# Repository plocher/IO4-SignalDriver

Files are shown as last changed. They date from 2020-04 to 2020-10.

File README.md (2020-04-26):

# IO4-SignalDriver
## License: CERN Open Hardware Licence v1.2

IO4 Output adapter driver for a 2-head signal mast

Takes an IO4-Output and drives 2x 3-LED common Anode signal heads using a demultiplexor logic chip.

Designed in conjunction with Jay Beckham for his South Shore Lines layout

Circuit testing:
  * The board needs to share a common ground with the remote controller (CMRI SMINI...) as the RJ45 only carries control signals
  * Drive the board with 5V DC through the IO4 connection
  * Signal heads / LEDs are "common anode" - pin4 of the signal head connector is VCC, the "colors" pins are driven LOW to energize the LED.
  * All control lines are pulled up logically on the signal driver board.
  * The board can drive 2x signal heads, each with R, Y, G and DARK aspects
      * Control signals 1 & 2 and  3 & 4, each control one head:
          : 00 - Green
          : 01 - Yellow
          : 10 - Red
          : 11 - Dark
  * The discrete resistors set a safe limit on the current allowed to the LED, and the trimmer pots can be used to further adjust the brightness.
  * The exact value depends on the specific attributes of the LED variety being used - specifically the forward voltage drop across the device. This info is found in the data sheet for the LED in question, or can be found experimentally.
      * Example:  with a 5v supply and a LED that drops 2.2v, the resistor sees (5-2.2 = 2.8v).  If we wish to limit the max current to 15mA, we need a fixed resistor of (2.8v / 0.015 = ~180 ohms).  If we add a 500 ohn trimmer resistor, that lets us adjust the current from 15mA max to about 4mA min.  High efficiency LEDs might need even LESS current, so upping the fixed resistor to 470R or even 1K0 might be appropriate.

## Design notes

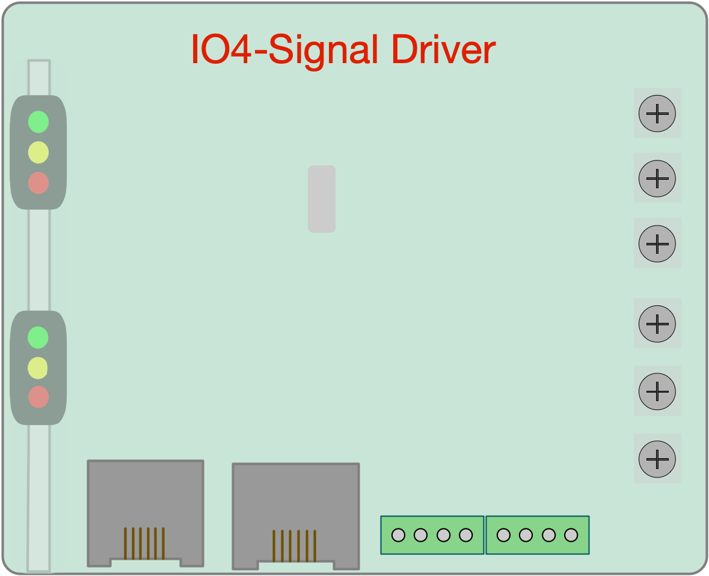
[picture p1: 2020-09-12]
IO4-SignalDriver-Graphic.png

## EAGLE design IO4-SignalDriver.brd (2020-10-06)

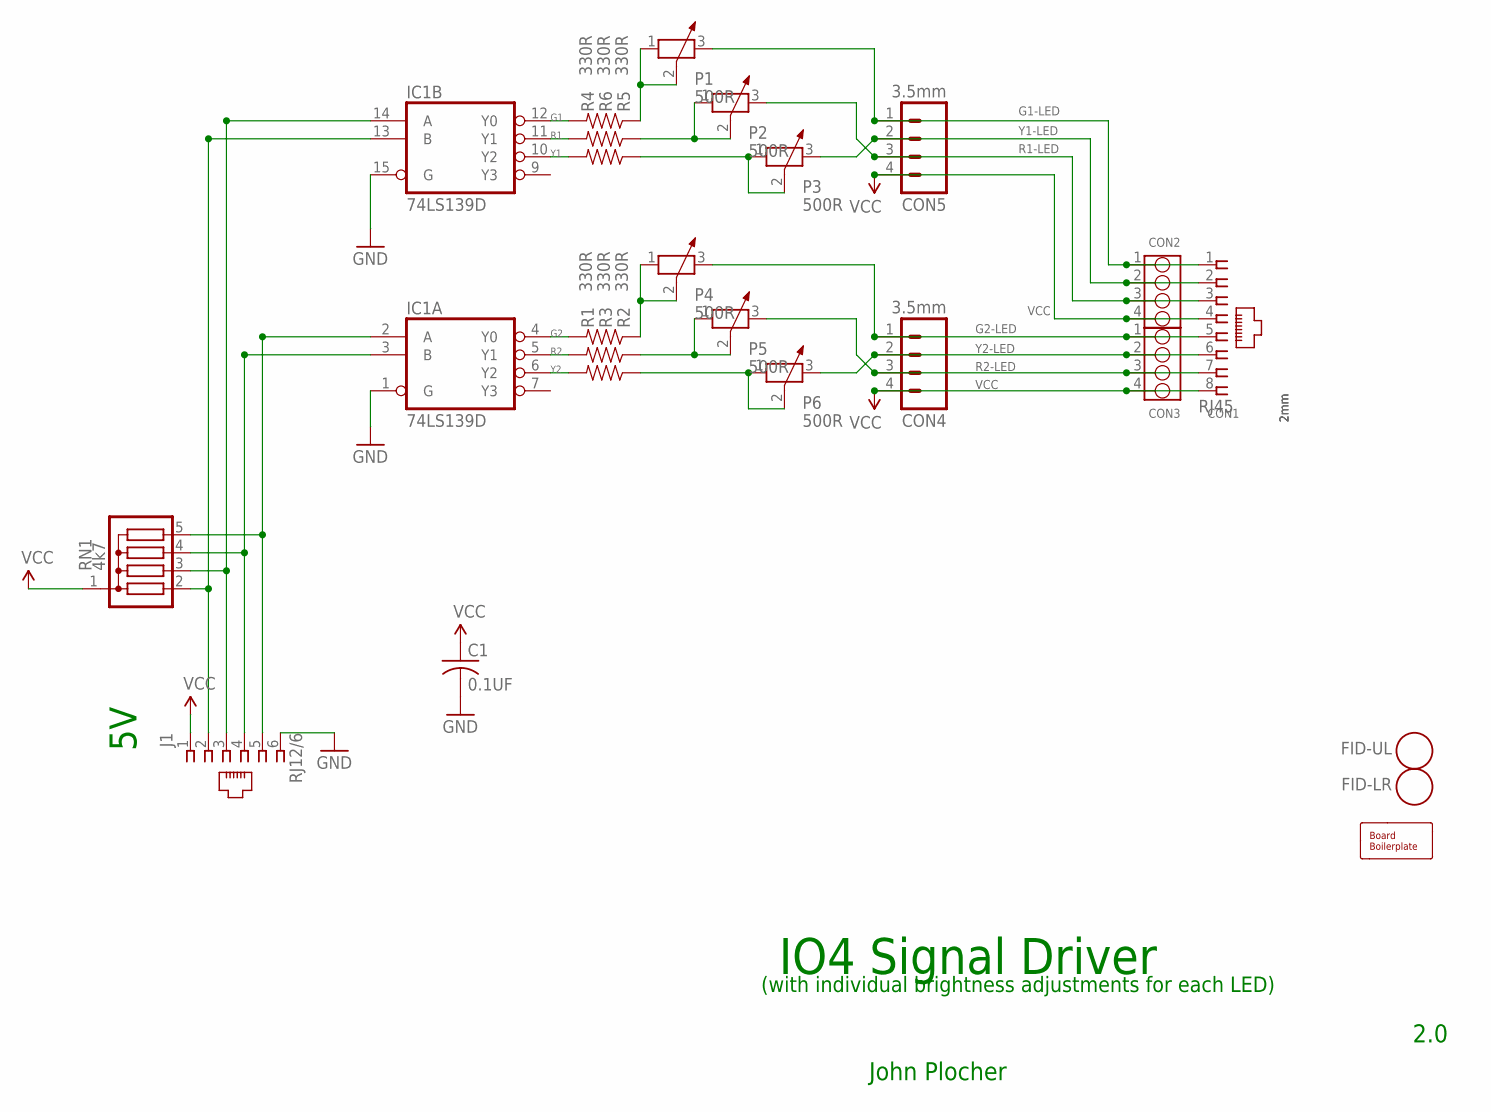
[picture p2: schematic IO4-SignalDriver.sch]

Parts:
BOARD1: BOARD; BOARD-DINRAIL-3.17INX10CM
C1: 0.1UF; 0603-CAP
CON1: RJ45; RJ45-NO-SHIELD
CON2, CON3: 2mm; 4P-2.0
CON4, CON5: 3.5mm; SCREWTERMINAL-3.5MM-4_LOCK
FID-LR: FIDUCIAL; FIDUCIAL_1MM
FID-UL: FIDUCIAL; FIDUCIAL_1MM
IC1: 74LS139D; SO16
J1: RJ12/6; RJ25-PANEL
P1, P2, P3, P4, P5, P6: 500R; P-3319
R1, R2, R3, R4, R5, R6: 330R; 0805-RES
RN1: 4k7; SIL5

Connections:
G1: IC1.12 (Y0), R4.2
G1-LED: CON1.1, CON2.1, CON5.1, P1.3
G1V: P1.1, P1.2, R4.1
G2: IC1.4 (Y0), R1.2
G2-LED: CON1.5, CON3.1, CON4.1, P4.3
G2V: P4.1, P4.2, R1.1
GND: C1.2, IC1.1 (G), IC1.8 (GND), IC1.15 (G), J1.6
unnamed: IC1.2 (A), J1.5, RN1.5
unnamed: IC1.3 (B), J1.4, RN1.4
unnamed: IC1.14 (A), J1.3, RN1.3
unnamed: IC1.13 (B), J1.2, RN1.2
R1: IC1.11 (Y1), R6.2
R1-LED: CON1.3, CON2.3, CON5.3, P2.3
R1V: P2.1, P2.2, R6.1
R2: IC1.5 (Y1), R3.2
R2-LED: CON1.7, CON3.3, CON4.3, P5.3
R2V: P5.1, P5.2, R3.1
VCC: C1.1, CON1.4, CON1.8, CON2.4, CON3.4, CON4.4, CON5.4, IC1.16 (VCC), J1.1, RN1.1
Y1: IC1.10 (Y2), R5.2
Y1-LED: CON1.2, CON2.2, CON5.2, P3.3
Y1V: P3.1, P3.2, R5.1
Y2: IC1.6 (Y2), R2.2
Y2-LED: CON1.6, CON3.2, CON4.2, P6.3
Y2V: P6.1, P6.2, R2.1

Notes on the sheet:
(with individual brightness adjustments for each LED)
John Plocher
2.0
IO4 Signal Driver

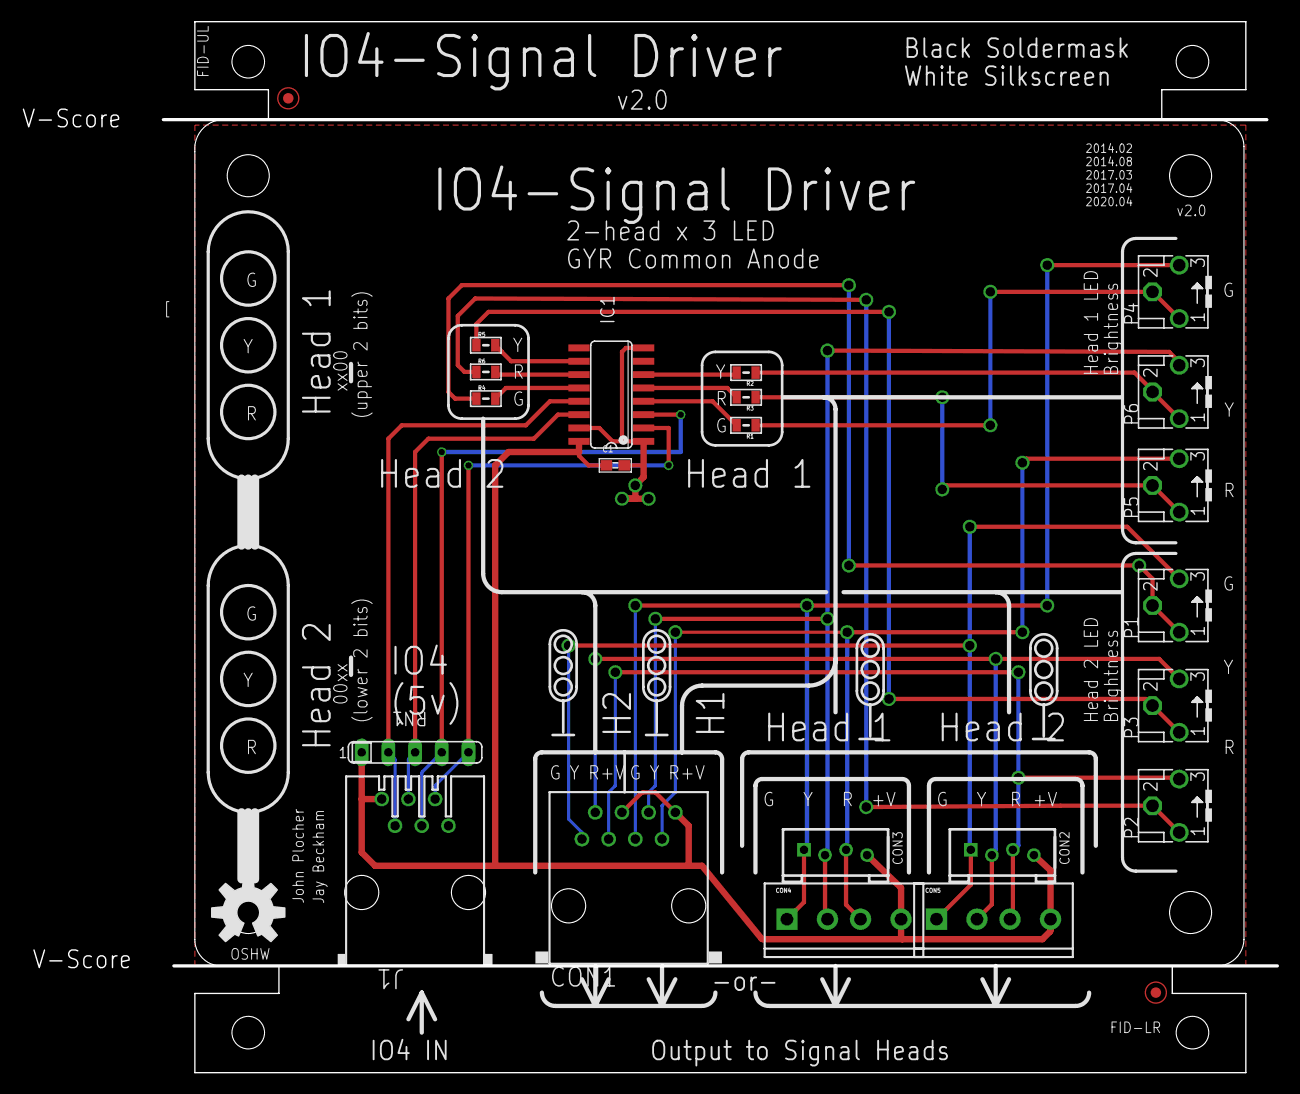
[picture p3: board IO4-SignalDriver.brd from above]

Board: 2 copper layers, 106.0 x 100.0 mm, 25 parts (0 on the bottom side), 24 nets.

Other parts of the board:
U$2: OSHW; OSHW-LOGO-L

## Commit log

2020-04-26 Initial version
    [IO4-SignalDriver.brd, IO4-SignalDriver.sch]
2020-04-26 convert to SMT, add 2mmx4 headers
    [IO4-SignalDriver.brd, IO4-SignalDriver.sch]
2020-04-26 changed silkscreen version info
    [IO4-SignalDriver.brd, IO4-SignalDriver.sch]
2020-04-26 removed unused sch sheet
    [IO4-SignalDriver.sch]
2020-08-12 Black soldermask
    [IO4-SignalDriver.brd, IO4-SignalDriver.sch]
2020-08-12 FID placement & SPCoast update
    [IO4-SignalDriver.brd, IO4-SignalDriver.sch]
2020-10-05 added values for connectors
    [IO4-SignalDriver.brd, IO4-SignalDriver.sch]
2020-10-06 normalized values
    [IO4-SignalDriver.brd, IO4-SignalDriver.sch]
